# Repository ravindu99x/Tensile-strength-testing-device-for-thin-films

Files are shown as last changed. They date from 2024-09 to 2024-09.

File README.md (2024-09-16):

# Tensile-strength-testing-device-for-thin-films
A low-cost Universal Testing Machine (UTM) for material characterization through tensile testing. Uses a stepper motor and load cell to measure force and displacement, with a Python Tkinter GUI for control and real-time stress-strain visualization. Supports speeds of 1.0-8.0 mm/min and a max load of 50N. Ideal for research and education.

Universal testing machines are tools that provide mathematical models that allow the study of the strength of materials, giving fundamental information for the mechanical characterization of materials, by obtaining physical and mechanical properties that are the basis for the sizing of any system or mechanical element. The basis of these destructive mechanical studies are tensile tests, which are the primary tool for studying the behavior of the material. In the present work, the design and construction of a low-cost, low-scale universal testing machine was carried out, and tensile experimental tests on nano fiber mats were conducted. The tensile testing machine consists of a stepper motor as an actuator, a load-cell, a load-cell amplifier, a data acquisition system and the 3D printed machine frame. The detected load-cell signal is amplified by the HX711 amplifier and is sent to the data acquisition (DAQ) system. The DAQ system with Python based Tkinter GUI software receives the signals from the load-cell and displacement from motor rotations, then plots the real-time stress-strain curve. Using this testing machine, it is possible to conduct tensile tests on miniature tensile specimens (thin films) at speeds of 1.0-8.0 mm/min. The maximum load it supports is 50 N, with a stroke range of 0 to 400 mm. Testing results in force and displacement with a deviation of ±2.5% of the real values can be measured. From the results obtained, it can be concluded that the machine developed in this work can be used to perform tensile tests on nano fiber mats with reliable results. The approximate cost of the constructed UTM is 100 US dollars.

"Universal Tensile Testing Machine VERSION TWO" is available under a Creative Commons CC BY-NC-SA 4.0 license from Instructables at https://www.instructables.com/Universal-Tensile-Testing-Machine-VERSION-TWO/. For details of the license, see https://creativecommons.org/licenses/by-nc-sa/4.0/. Modifications made by [LakshanHDR].

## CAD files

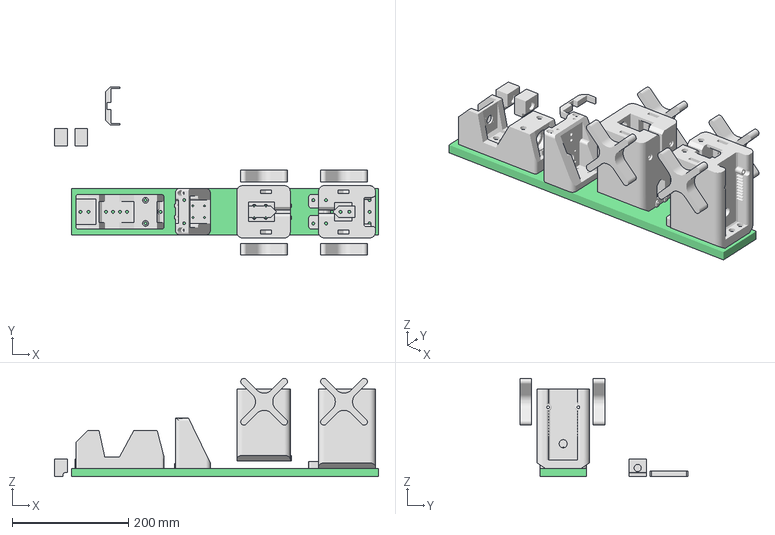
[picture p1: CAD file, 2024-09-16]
3D Printing Designs/Assembled.3mf
557.3 x 289.8 x 169.1 mm

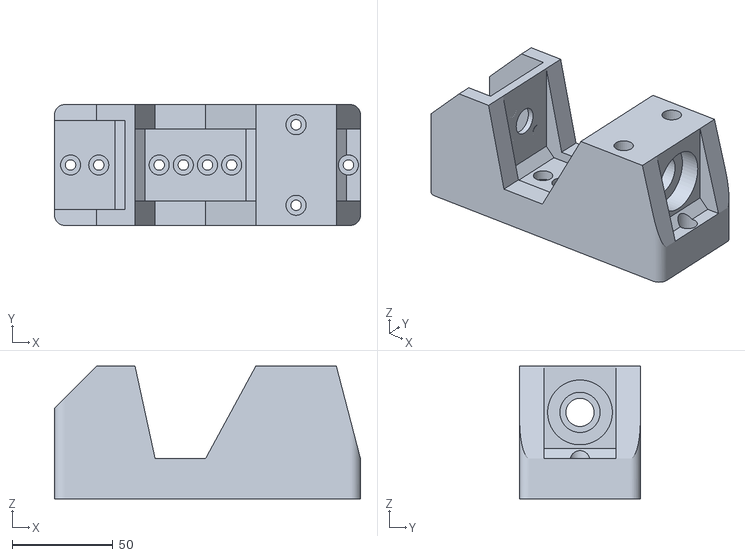
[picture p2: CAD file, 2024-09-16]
3D Printing Designs/Stepper+Motor+Mount+Mk4+Long+v11 v1.stl
152.0 x 60.0 x 66.0

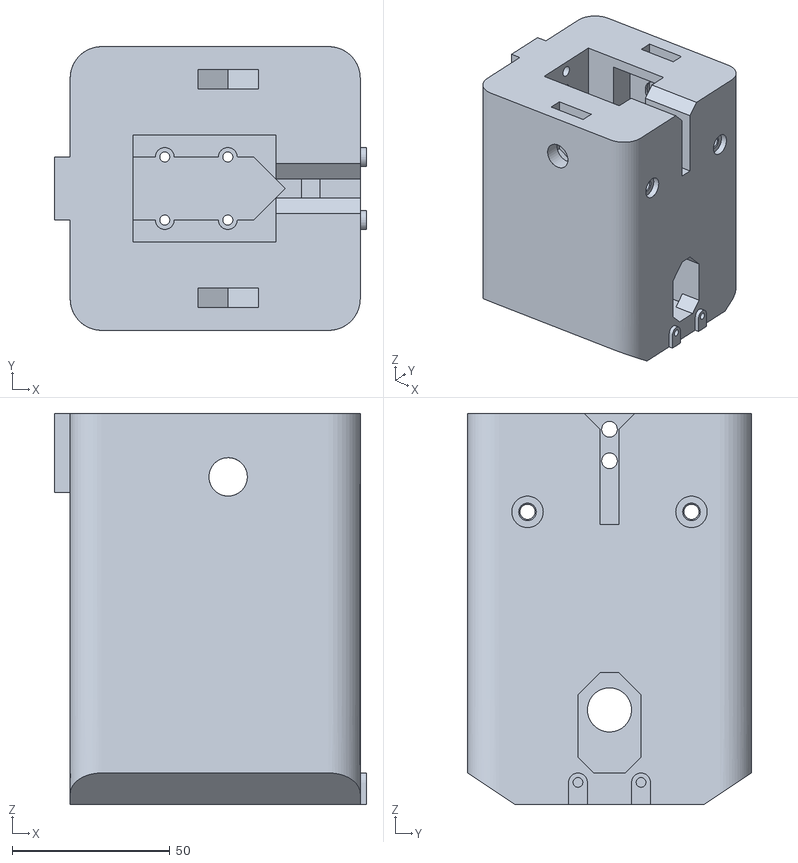
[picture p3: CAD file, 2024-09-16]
3D Printing Designs/Moving+Grip_NEW.stl
99.0 x 90.0 x 124.0

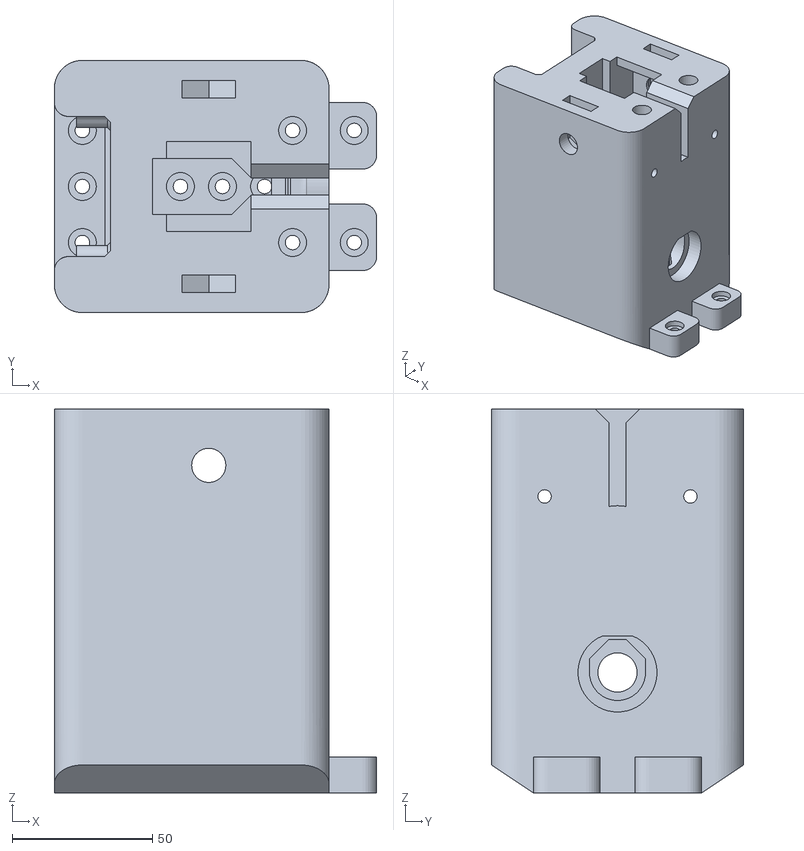
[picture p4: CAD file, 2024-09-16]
3D Printing Designs/Stationary+Grip+Mk3+v37 v0.stl
115.0 x 90.0 x 137.0

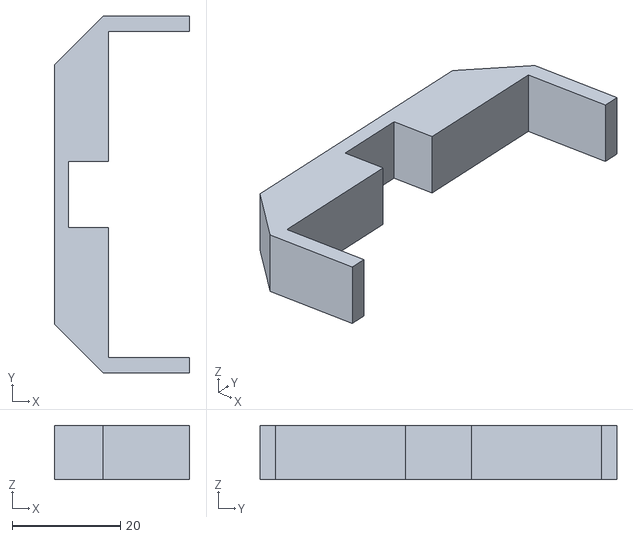
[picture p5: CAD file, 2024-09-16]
3D Printing Designs/Tool+1.stl
25.0 x 66.0 x 10.00

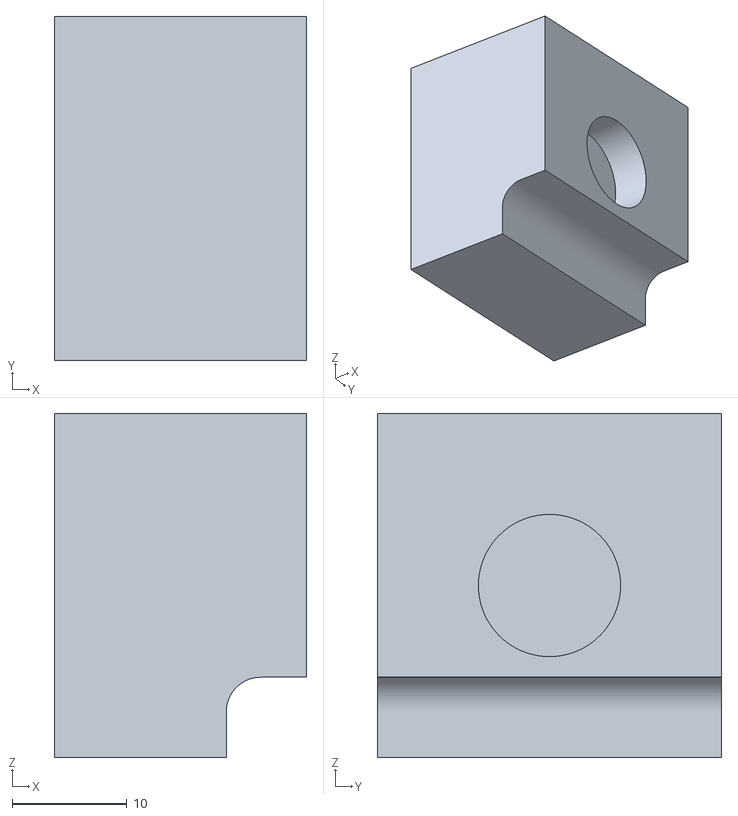
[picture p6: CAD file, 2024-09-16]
3D Printing Designs/Grip+Block+v5.stl
22.0 x 30.0 x 30.0

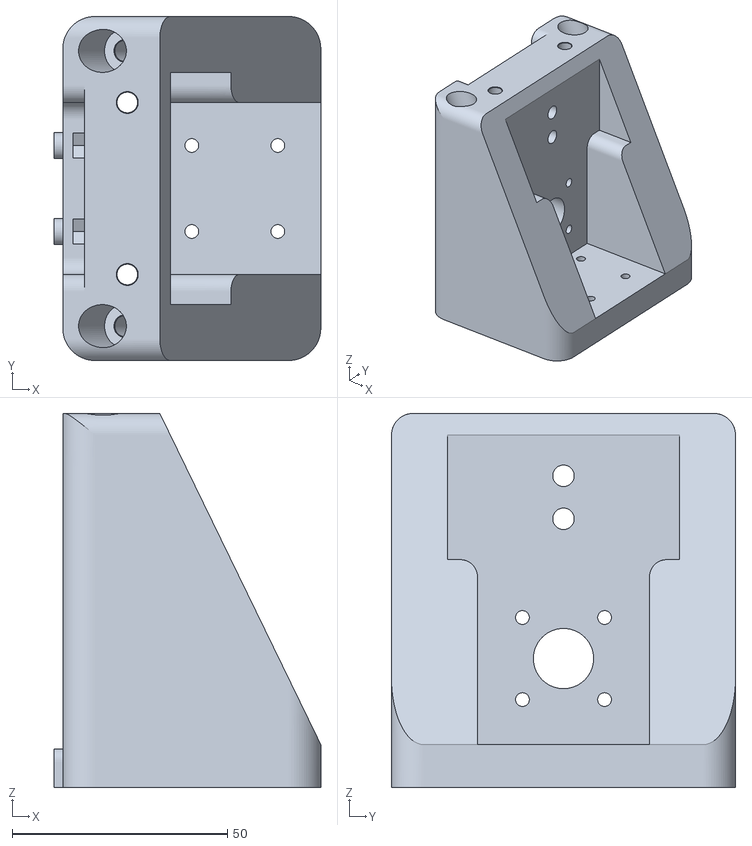
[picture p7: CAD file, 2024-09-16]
3D Printing Designs/Moving+Load+Cell+Mount+Mk2+v23 v1_stl.stl
62.0 x 80.0 x 87.0

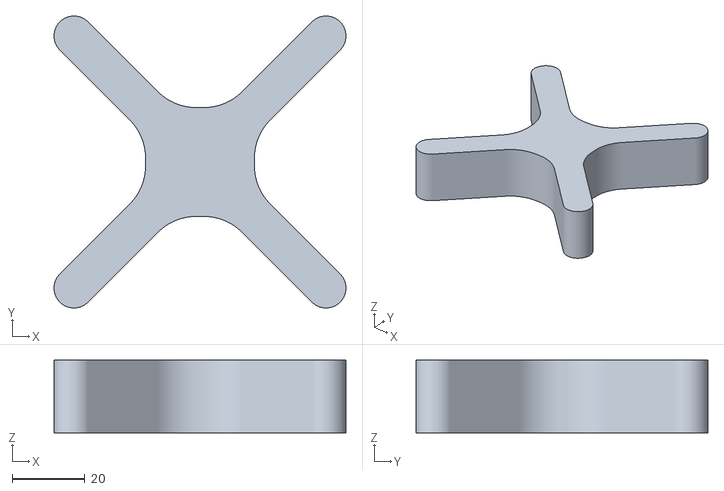
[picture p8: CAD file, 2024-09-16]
3D Printing Designs/Grip+Screw+Head+v8.stl
80.5 x 80.5 x 20.0

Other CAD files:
Sample Dimensions/ASTM D638-14.dwg
3D Printing Designs/Moving+Grip_NEW.f3d
3D Printing Designs/Moving+Load+Cell+Mount+Mk2+v23 v1.f3d
3D Printing Designs/Stationary+Grip+Mk3+v37.f3d
3D Printing Designs/Stepper+Motor+Mount+Mk4+Long+v11 v0.f3d

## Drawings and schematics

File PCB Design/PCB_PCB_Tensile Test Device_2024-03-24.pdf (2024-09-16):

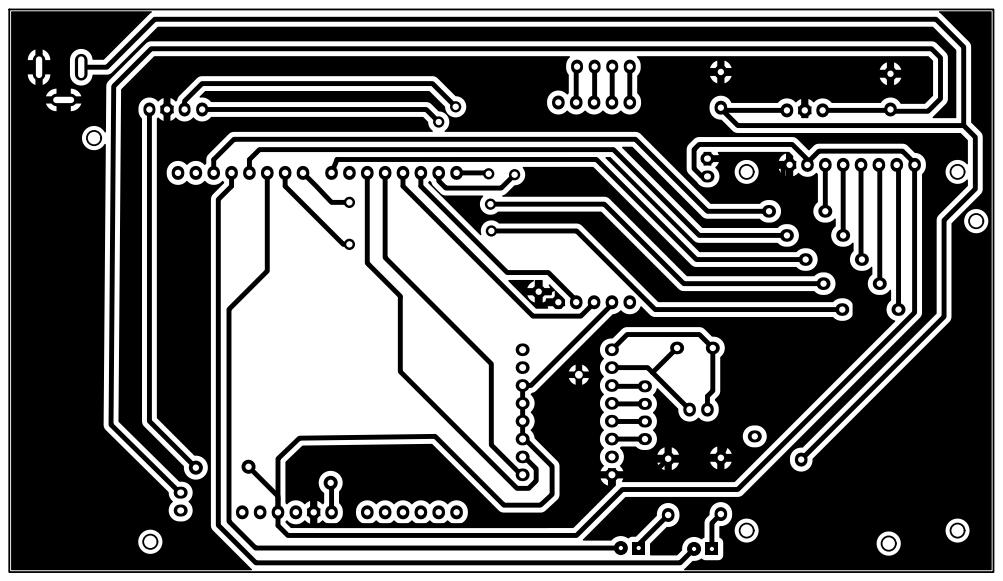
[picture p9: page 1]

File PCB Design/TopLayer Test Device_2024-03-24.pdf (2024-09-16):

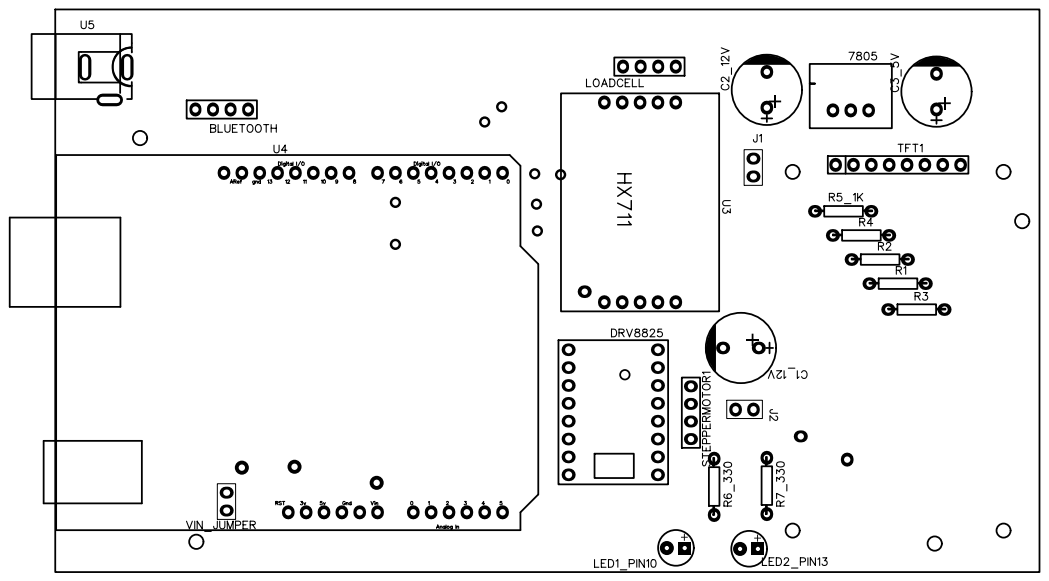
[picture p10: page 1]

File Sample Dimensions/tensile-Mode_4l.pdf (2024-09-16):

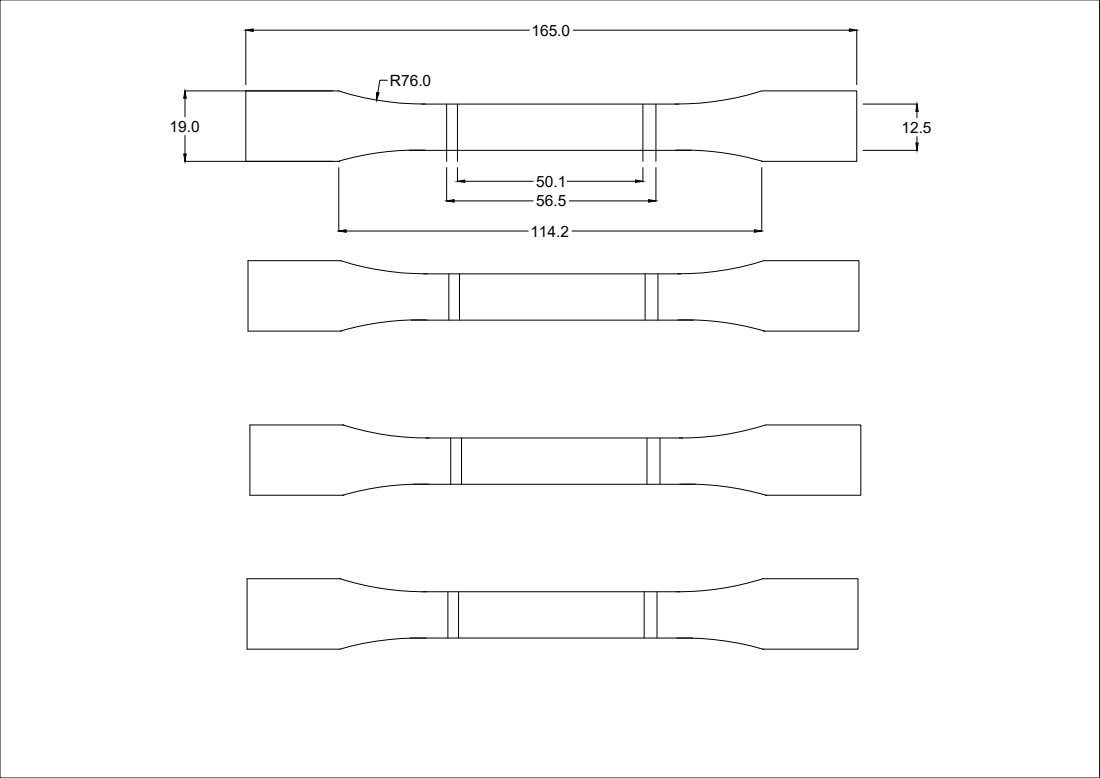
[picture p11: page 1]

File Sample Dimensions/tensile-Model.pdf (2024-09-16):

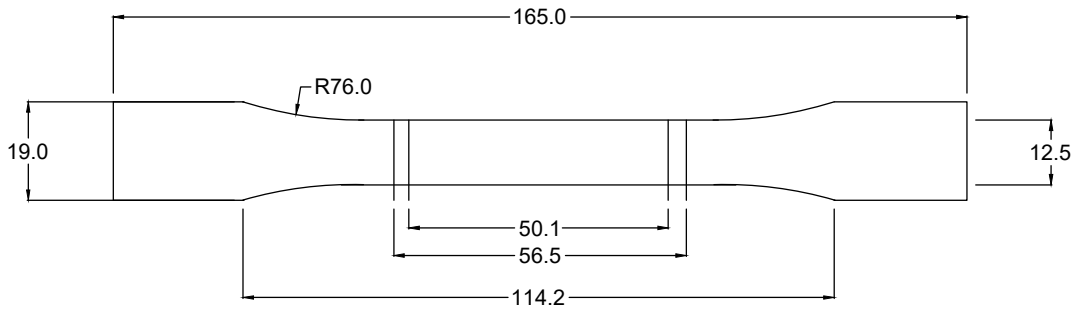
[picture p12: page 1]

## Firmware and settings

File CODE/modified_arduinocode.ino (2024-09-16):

#include "HX711.h"
#include "AccelStepper.h"

//LCD Display
#include <Adafruit_GFX.h>    // Core graphics library
#include <Adafruit_ST7735.h> // Hardware-specific library
#include <SPI.h>

#define TFT_CS     9
#define TFT_RST    7 
#define TFT_DC     8

Adafruit_ST7735 tft = Adafruit_ST7735(TFT_CS,  TFT_DC, TFT_RST);
#define TFT_SCLK 13   
#define TFT_MOSI 11   

float p = 3.1415926;

// Load cell settings
#define calibration_factor 394
#define LOADCELL_DOUT_PIN  3
#define LOADCELL_SCK_PIN  2
HX711 scale;

// Stepper motor settings
#define dirPin 4
#define stepPin 5
#define motorInterfaceType 1
double step_length = 0.008/6000;
float sample_length = 0.11;
float sample_width = 0.011;
AccelStepper stepper = AccelStepper(motorInterfaceType, stepPin, dirPin);

//LED Indicators
#define Standby_LED 10
#define running_LED 12
long count= 0;
bool testRunning = false;

// Add global variables for motor speed and sample thickness
int motorSpeed = 1000; // Default speed
double sampleThickness = 0.1; // Default thickness in mm

void setup() {
  //LCD Display
  tft.initR(INITR_BLACKTAB);   // initialize a ST7735S chip, black tab
  tft.fillScreen(ST7735_RED);
  testdrawtext(5, 25, "EPL Mini Project", ST7735_WHITE);
  testdrawtext(5, 35, "Tensile Testing", ST7735_WHITE);
  testdrawtext(5, 45, "s14832", ST7735_WHITE);
  delay(2000);
  tft.fillScreen(ST7735_BLUE);
  tft.setTextSize(1.5);
  testdrawtext(5, 55, "Processing...", ST7735_WHITE);
  delay(2000);
  tft.fillScreen(ST7735_WHITE);
  testdrawtext(5, 55, "Press Start...", ST7735_BLACK);
  delay(2000);
  
  pinMode(Standby_LED, OUTPUT);
  pinMode(running_LED, OUTPUT);
  
  Serial.begin(115200);
  scale.begin(LOADCELL_DOUT_PIN, LOADCELL_SCK_PIN);
  scale.set_scale(calibration_factor);
  scale.tare();
  
  stepper.setCurrentPosition(0);
  stepper.setMaxSpeed(8000);
  stepper.setSpeed(0);
  digitalWrite(Standby_LED, HIGH);
}

void loop() {

  // Check for new commands
  if (Serial.available() > 0) {
    String command = Serial.readStringUntil('\n');
    if (command.startsWith("START")) {
      // Split the command by commas
      int firstCommaIndex = command.indexOf(',');
      int secondCommaIndex = command.indexOf(',', firstCommaIndex + 1);

      String speedStr = command.substring(firstCommaIndex + 1, secondCommaIndex);
      String thicknessStr = command.substring(secondCommaIndex + 1);

      // Convert speed and thickness to integers
      motorSpeed = speedStr.toInt();
      sampleThickness = thicknessStr.toFloat();

      testRunning = true;
      tft.fillScreen(ST7735_GREEN);
      
      testdrawtext(5, 25, "EPL Mini Project", ST7735_BLACK);
      testdrawtext(5, 35, "Tensile Testing", ST7735_BLACK);
      testdrawtext(5, 45, "s14832", ST7735_BLACK);
      testdrawtext(5, 75, "RUNNING...", ST7735_BLACK);
      testdrawtext(5, 85, "Collecting data...", ST7735_BLACK);
      testdrawtext(5, 95, "This may take a while...", ST7735_BLACK);
//      stepper.setSpeed(8000);
//      stepper.run();
      digitalWrite(Standby_LED, LOW);
      digitalWrite(running_LED, HIGH);

      
    } else if (command == "RESET") {
      testRunning = false;
      tft.fillScreen(ST7735_YELLOW);
      testdrawtext(5, 25, "EPL Mini Project", ST7735_BLACK);
      testdrawtext(5, 35, "Tensile Testing", ST7735_BLACK);
      testdrawtext(5, 45, "s14832", ST7735_BLACK);
      
      testdrawtext(5, 65, "DEVICE RESETTING...", ST7735_BLACK);
      testdrawtext(5, 75, "Please save files before closing the window...", ST7735_BLACK);
      testdrawtext(5, 115, "DEVICE READY...", ST7735_BLACK);
      stepper.moveTo(0);
      count = 0;
//      stepper.setSpeed(8000); // Adjust as needed
//      stepper.run();
      digitalWrite(running_LED, LOW);
      digitalWrite(Standby_LED, HIGH);
    }
  }

  // Run test if started
  if (testRunning) {
    stepper.setSpeed(-3300);
    if (stepper.distanceToGo() == 0) {
      // Example: move back and forth
      long newPos = (stepper.currentPosition() == 0) ? 6400 : 0;
      stepper.moveTo(newPos);
    }
    count = stepper.currentPosition();
    // Collect and send data
    double sensorValue1 = (step_length * count) / sample_length; // Adjust sample_length as needed
//    double sensorValue1 =  count; // Adjust sample_length as needed
    double area = sample_width*sampleThickness;
    double sensorValue2 = (scale.get_units()/(1000*area))*9.81;
//    double sensorValue2 = (scale.get_units()/1000)*10;
    if (sensorValue2 > -1) {
//      stepper.setSpeed(8000);
//      stepper.run();
      Serial.print(abs(sensorValue1), 7);
      Serial.print(", ");
      Serial.println(sensorValue2, 2);
//      delay(10);
    }
    stepper.run();
  } else if (stepper.distanceToGo() != 0) {
    // Continue moving to the reset position if not there yet
    stepper.setSpeed(3300); // Adjust as needed
    stepper.run();
  }
  
  delay(10); // Small delay to stabilize loop, adjust as needed
}

void testdrawtext(int wid, int hei, char *text, uint16_t color) {
  tft.setCursor(wid, hei);
  tft.setTextColor(color);
  tft.setTextWrap(true);
  tft.print(text);
}

//void testdrawScreenData(){
//  tft.setCursor(0,20);
//  tft.println("Screen Data:");
//  tft.print("Screen Width: ");
//  tft.println(tft.width());
//  tft.print("Screen Height: ");
//  tft.println(tft.height());
//}

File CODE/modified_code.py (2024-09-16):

import tkinter as tk
from tkinter import ttk
import serial
import serial.tools.list_ports
from matplotlib.backends.backend_tkagg import FigureCanvasTkAgg
from matplotlib.figure import Figure
import csv

# Use a larger font size for buttons
button_font = ('Helvetica', 14)


# Function to list available COM ports
def list_com_ports():
    ports = serial.tools.list_ports.comports()
    return [port.device for port in ports]


# Global variable for serial connection
ser = None

# Lists to store sensor data
sensorValue1_data = []
sensorValue2_data = []

# Set up the GUI
root = tk.Tk()
root.title("Tensile_test_EPL_Mini_project_s14832")

# Dropdown menu for COM port selection
com_port_var = tk.StringVar(root)
com_ports = list_com_ports()
com_port_var.set(com_ports[0] if com_ports else "")
com_port_dropdown = ttk.Combobox(root, textvariable=com_port_var, values=com_ports, state="readonly")
com_port_dropdown.pack(side=tk.TOP, fill=tk.X)


# Function to update the COM port dropdown
def update_com_ports():
    com_ports = list_com_ports()
    com_port_var.set(com_ports[0] if com_ports else "")
    com_port_dropdown['values'] = com_ports


# Function to connect to the selected COM port
def connect_to_com_port():
    global ser
    selected_port = com_port_var.get()
    if selected_port:
        try:
            if ser is not None:
                ser.close()  # Close existing connection if any
                ser = None   # Reset the global serial variable
            ser = serial.Serial(selected_port, 115200, timeout=1)
            start_test_button['state'] = 'normal'  # Enable the "Start Test" button
            clear_plot()  # Optionally clear the plot when connecting to a new port
            root.after(1, update_plot)  # Restart the plotting loop
        except serial.SerialException as e:
            print(f"Failed to connect on {selected_port}. Error: {e}")


# Connect button
connect_button = ttk.Button(root, text="Connect", command=connect_to_com_port, width=20, style='my.TButton')
connect_button.pack(side=tk.TOP, fill=tk.X, pady=5)

# Refresh COM ports button
refresh_button = ttk.Button(root, text="Refresh Ports", command=update_com_ports, width=20, style='my.TButton')
refresh_button.pack(side=tk.TOP, fill=tk.X, pady=5)

# Frame for plot
frame = ttk.Frame(root)
frame.pack(fill=tk.BOTH, expand=True)

# Matplotlib figure and canvas for plotting
fig = Figure()
ax = fig.add_subplot(111)
ax.set_xlabel('Strain (ε)')
ax.set_ylabel('Stress (σ)')
ax.set_title('Stress-Strain Curve')  # Setting the title
ax.grid(True)  # Turning on the grid
line, = ax.plot(sensorValue1_data, sensorValue2_data, linestyle='-')

canvas = FigureCanvasTkAgg(fig, master=frame)
canvas_widget = canvas.get_tk_widget()
canvas_widget.pack(fill=tk.BOTH, expand=True)


# Function to update the plot
def update_plot():
    if ser and ser.isOpen() and ser.in_waiting:  # Check if ser is not None and the port is open
        data_line = ser.readline().decode('utf-8').strip()
        if data_line:
            try:
                sensorValues = list(map(float, data_line.split(', ')))
                if len(sensorValues) == 2:
                    sensorValue1_data.append(sensorValues[0])
                    sensorValue2_data.append(sensorValues[1])
                    line.set_xdata(sensorValue1_data)
                    line.set_ydata(sensorValue2_data)
                    ax.relim()
                    ax.autoscale_view(True,True,True)
                    canvas.draw()
            except ValueError:
                pass  # Handle error if needed
    root.after(100, update_plot)  # Adjust the update rate as needed



# Modify the start_test function
def start_test():
    if ser:
        motor_speed = motor_speed_var.get()
        sample_thickness = sample_thickness_var.get()
        # Format the command with speed and thickness
        command = f"START,{motor_speed},{sample_thickness}\n"
        ser.write(command.encode())


# Function to reset the stepper motor position
def reset_motor_position():
    if ser:
        ser.write("RESET\n".encode())


# Function to clear the plot
def clear_plot():
    sensorValue1_data.clear()
    sensorValue2_data.clear()
    ax.cla()
    ax.set_xlabel('Strain (ε)')
    ax.set_ylabel('Stress (σ)')
    ax.set_title('Stress-Strain Curve')  # Setting the title
    ax.grid(True)  # Turning on the grid
    global line
    line, = ax.plot(sensorValue1_data, sensorValue2_data, linestyle='-')
    canvas.draw()


# Function to save collected data to a CSV file
def save_data():
    with open('sensor_data.csv', 'w', newline='') as file:
        writer = csv.writer(file)
        writer.writerow(['Strain', 'Stress'])
        for s1, s2 in zip(sensorValue1_data, sensorValue2_data):
            writer.writerow([s1, s2])


# Function to save the plot as a PNG file
def save_plot_as_png():
    fig.savefig('stress_strain_curve.png')

# Add input fields for motor speed and sample thickness
motor_speed_var = tk.IntVar(value=1000)  # Default speed
sample_thickness_var = tk.DoubleVar(value=0.0001)  # Default thickness in mm

# Add descriptive labels and larger entry fields for motor speed and sample thickness

# Label for Motor Speed
motor_speed_label = tk.Label(root, text="Motor Speed (Value in range: 500 to 3000):")
motor_speed_label.pack(side=tk.TOP, fill=tk.X)

# Entry for Motor Speed with a larger font
motor_speed_entry = ttk.Entry(root, textvariable=motor_speed_var, font=('Helvetica', 12))
motor_speed_entry.pack(side=tk.TOP, fill=tk.X, pady=(0, 5))

# Label for Sample Thickness
sample_thickness_label = tk.Label(root, text="Sample Thickness (m):")
sample_thickness_label.pack(side=tk.TOP, fill=tk.X)

# Entry for Sample Thickness with a larger font
sample_thickness_entry = ttk.Entry(root, textvariable=sample_thickness_var, font=('Helvetica', 12))
sample_thickness_entry.pack(side=tk.TOP, fill=tk.X, pady=(0, 10))

# Adjusting other GUI elements to match the new geometry
connect_button.pack(side=tk.TOP, fill=tk.X, pady=(0, 2))
refresh_button.pack(side=tk.TOP, fill=tk.X, pady=(2, 10))

# Ensure the frame (plot area) expands more significantly to improve visibility
frame.pack(fill=tk.BOTH, expand=True, padx=10, pady=10)

# Adjusting button sizes and layout
button_frame = ttk.Frame(root)  # A frame to contain control buttons for a cleaner layout
button_frame.pack(side=tk.BOTTOM, fill=tk.X, pady=(5, 0))

# Button to start the test
start_test_button = ttk.Button(root, text="Start Test", command=start_test, state='disabled', width=20, style='my.TButton')
start_test_button.pack(in_=button_frame, side=tk.LEFT, expand=True, padx=(5, 2))

# Reset motor position button
reset_motor_button = ttk.Button(root, text="Reset Motor Position", command=reset_motor_position, width=20, style='my.TButton')
reset_motor_button.pack(in_=button_frame, side=tk.LEFT, expand=True, padx=2)
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
